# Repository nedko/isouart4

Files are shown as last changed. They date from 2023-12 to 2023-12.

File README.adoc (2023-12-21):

:notitle:
:keywords: isouart4
:docinfo: private-head,private-header

= isouart4 - Galvanically Isolated USB attached Quad UART

isouart4 - OSHW Galvanically Isolated USB attached Quad UART

.WORK IN PROGRESS
[NOTE]
This is Work In Progress.

link:bom/ibom.html[BOM - Bill Of Materials]

link:isouart4_sch.pdf[Schematic PDF]

link:https://gitea.ladish.org/nedko/isouart4[Project files] for link:https://kicad.org/[KiCAD]

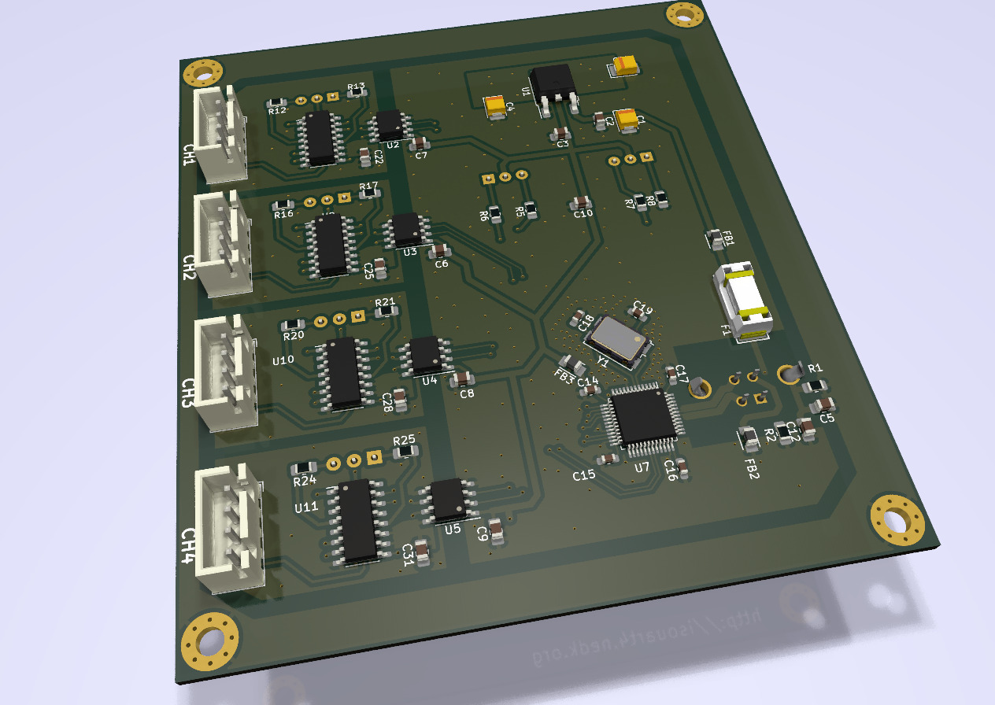
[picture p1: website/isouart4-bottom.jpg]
PCB bottom


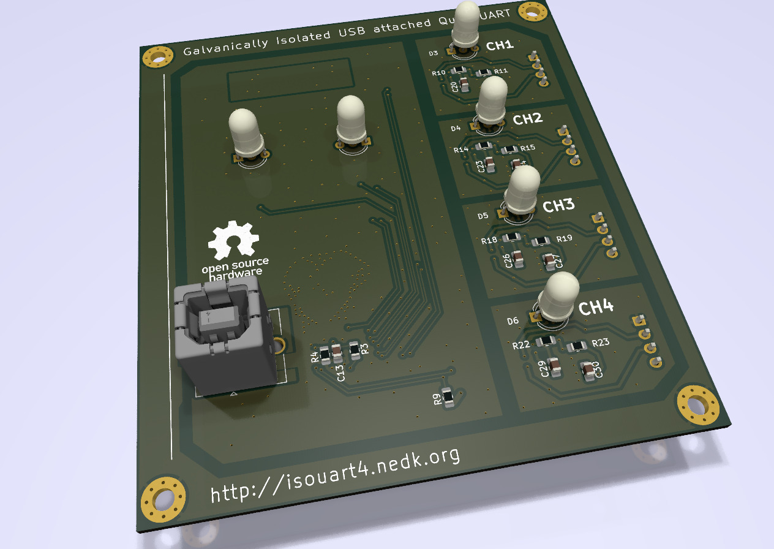
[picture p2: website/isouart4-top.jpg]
PCB top


== See also

 * link:https://github.com/hexeguitar/4WD_UART[4WD_UART by Piotr Zapart] is similar project that heavily influenced isouart4 design

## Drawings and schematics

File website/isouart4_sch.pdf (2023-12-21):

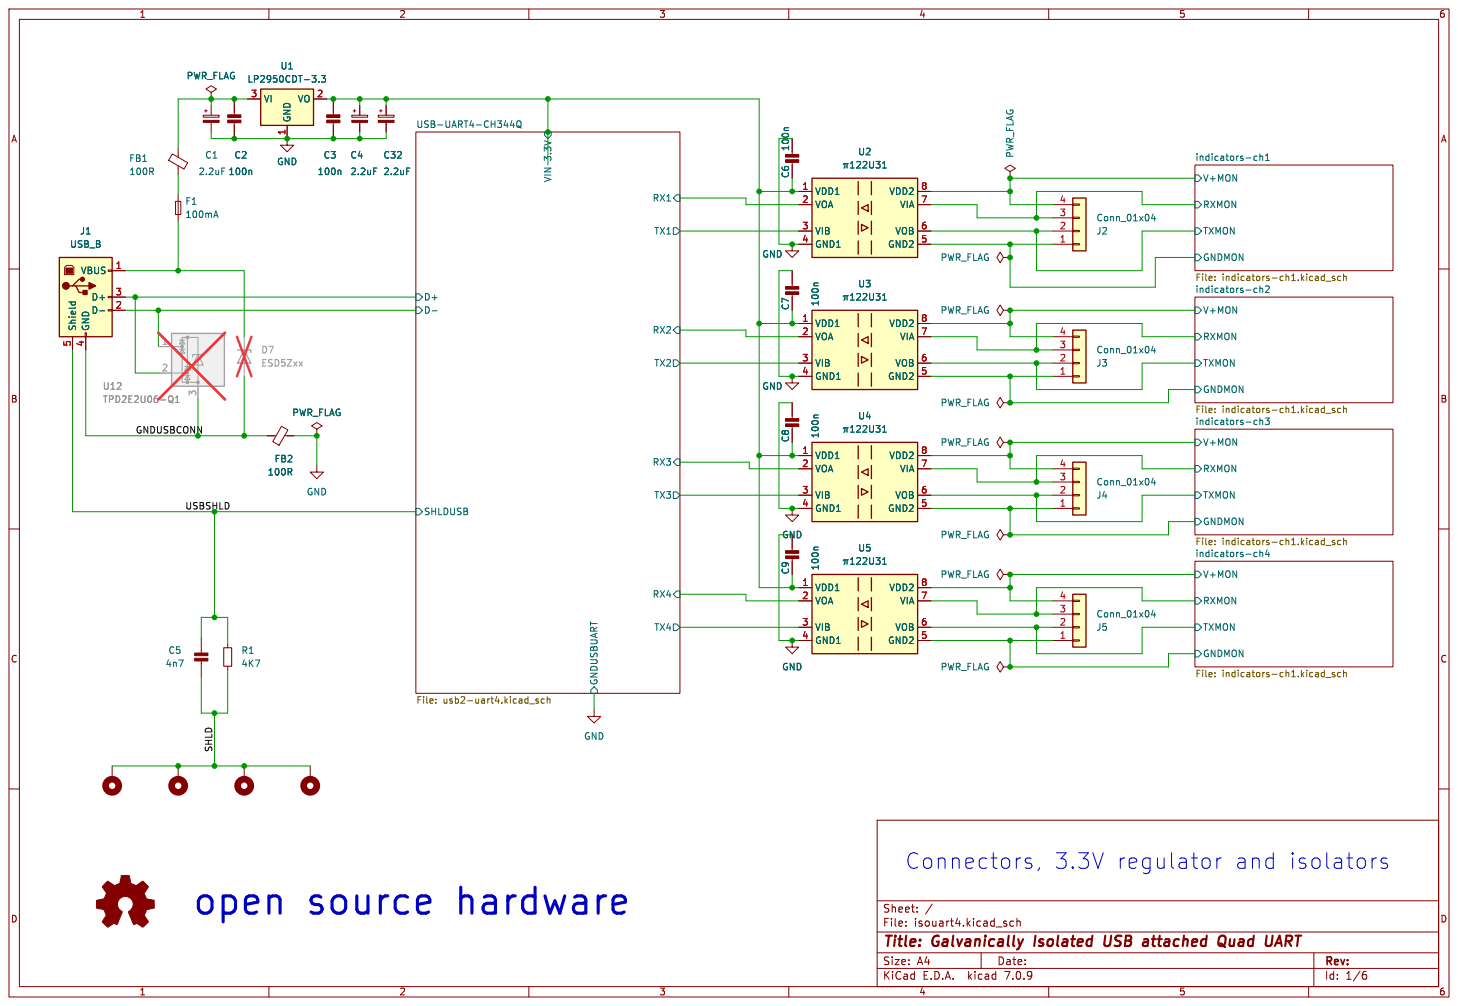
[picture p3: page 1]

indicators-ch3 File: indicators-ch1.kicad_sch RXMON

Id: 1/6 Title: Galvanically Isolated USB attached Quad UART

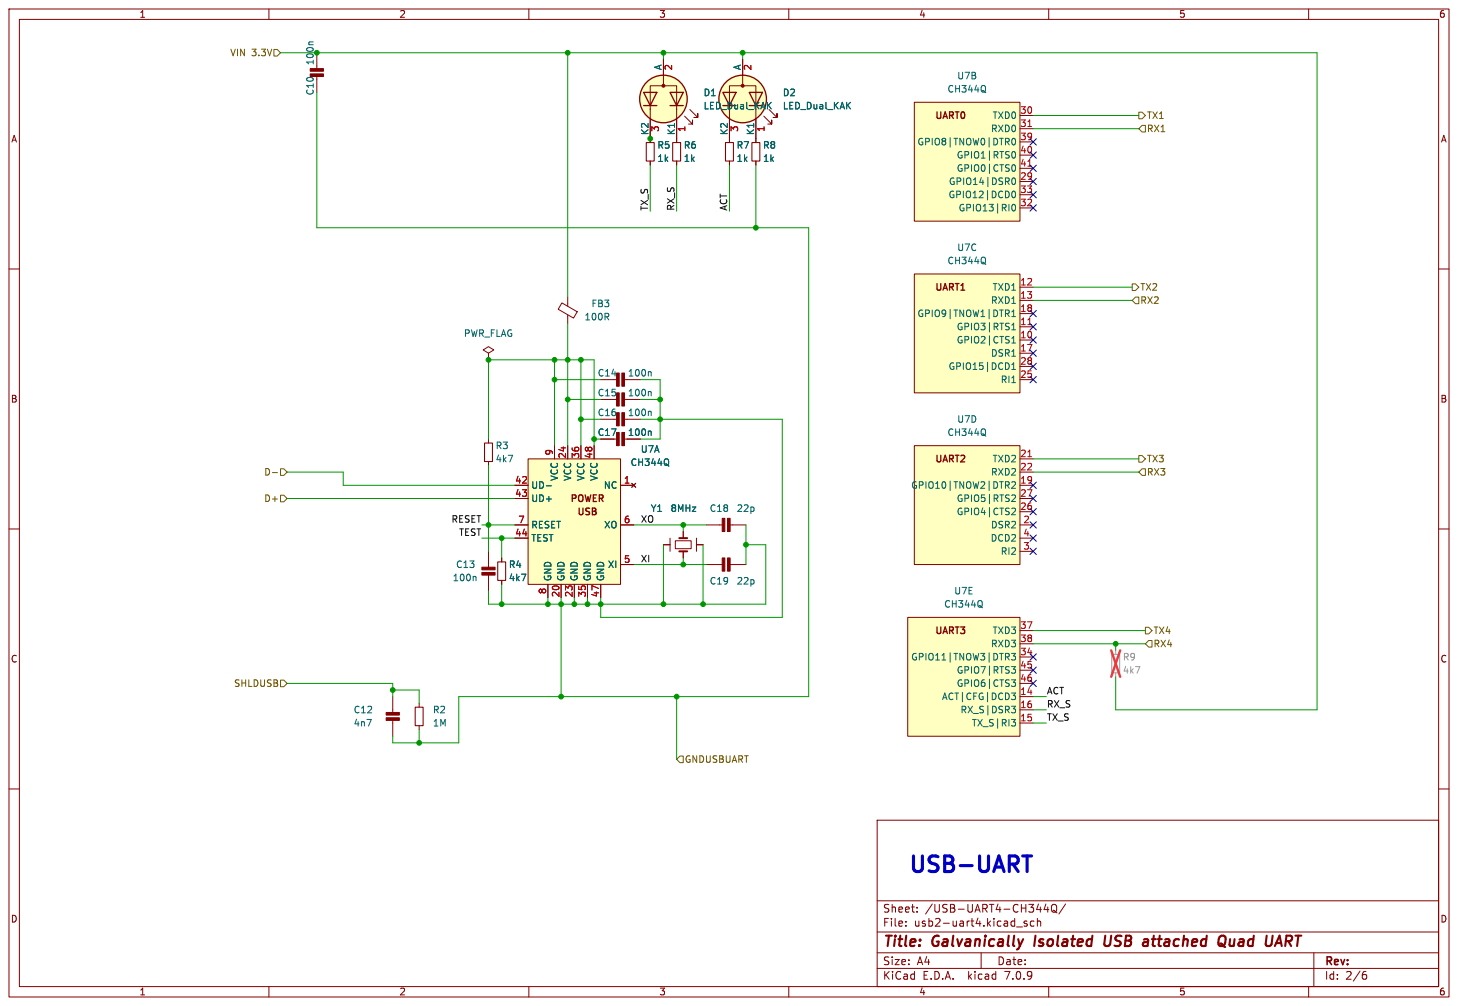
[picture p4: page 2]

File: usb2-uart4.kicad_sch Sheet: /USB-UART4-CH344Q/
Id: 2/6 Title: Galvanically Isolated USB attached Quad UART

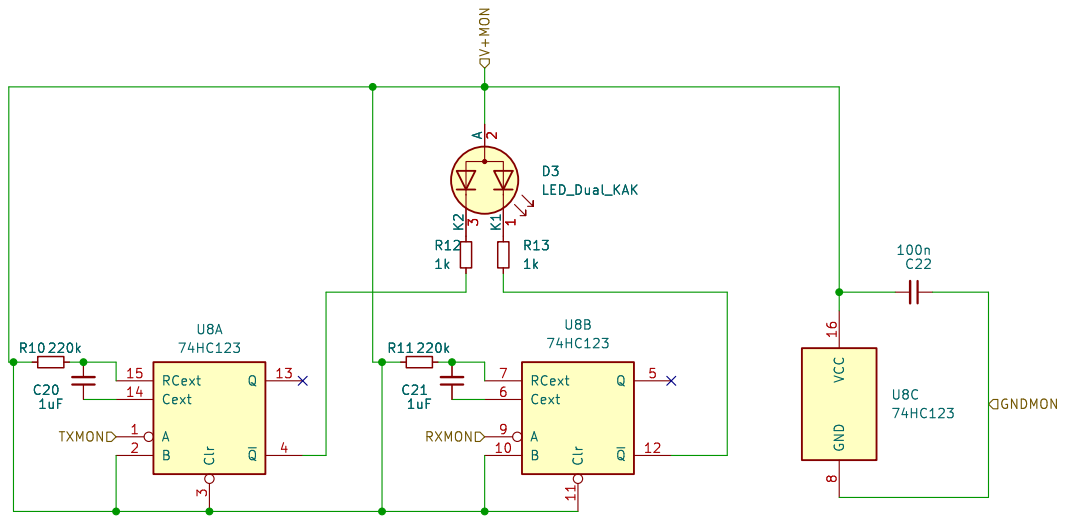
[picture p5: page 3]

File: indicators-ch1.kicad_sch Sheet: /indicators-ch1/ B

Id: 4/6 Title: Galvanically Isolated USB attached Quad UART

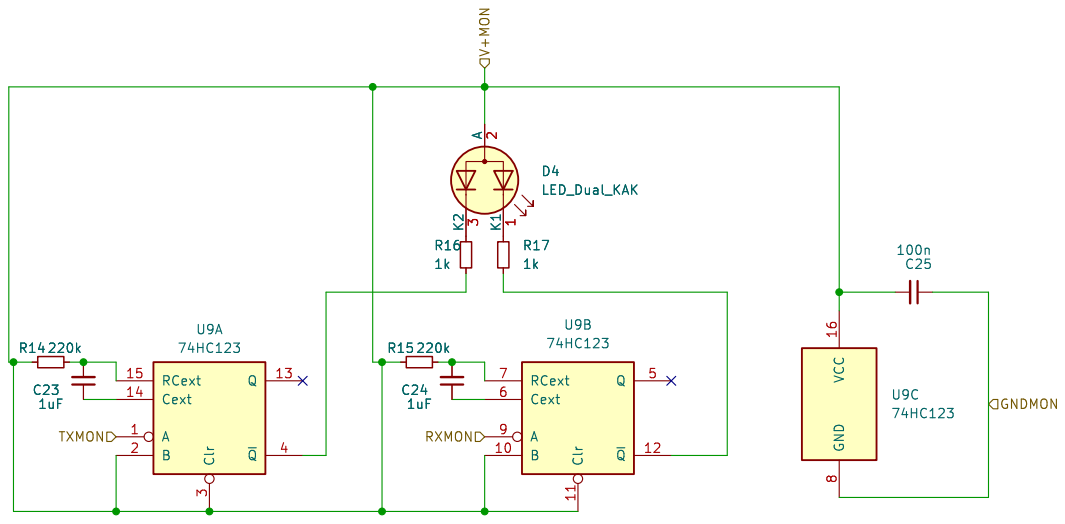
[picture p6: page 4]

File: indicators-ch1.kicad_sch Sheet: /indicators-ch2/ B

Id: 5/6 Title: Galvanically Isolated USB attached Quad UART

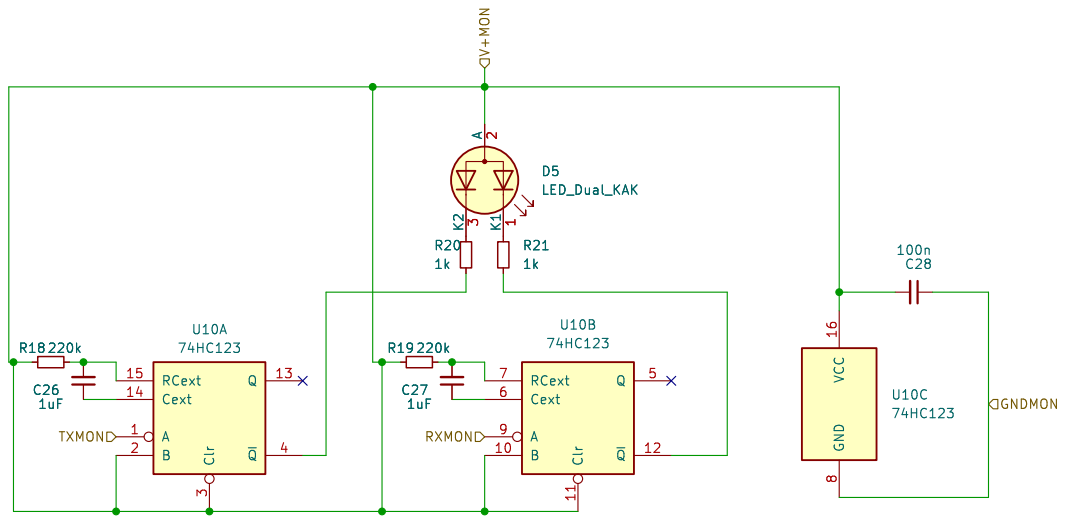
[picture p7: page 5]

File: indicators-ch1.kicad_sch Sheet: /indicators-ch3/ B

Id: 6/6 Title: Galvanically Isolated USB attached Quad UART

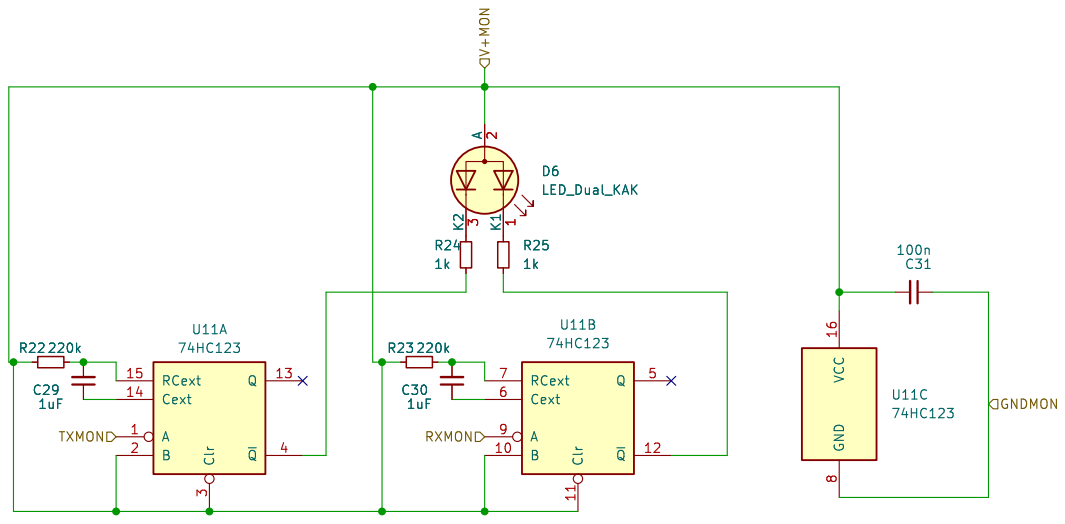
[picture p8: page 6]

File: indicators-ch1.kicad_sch Sheet: /indicators-ch4/ B

Id: 7/6 Title: Galvanically Isolated USB attached Quad UART

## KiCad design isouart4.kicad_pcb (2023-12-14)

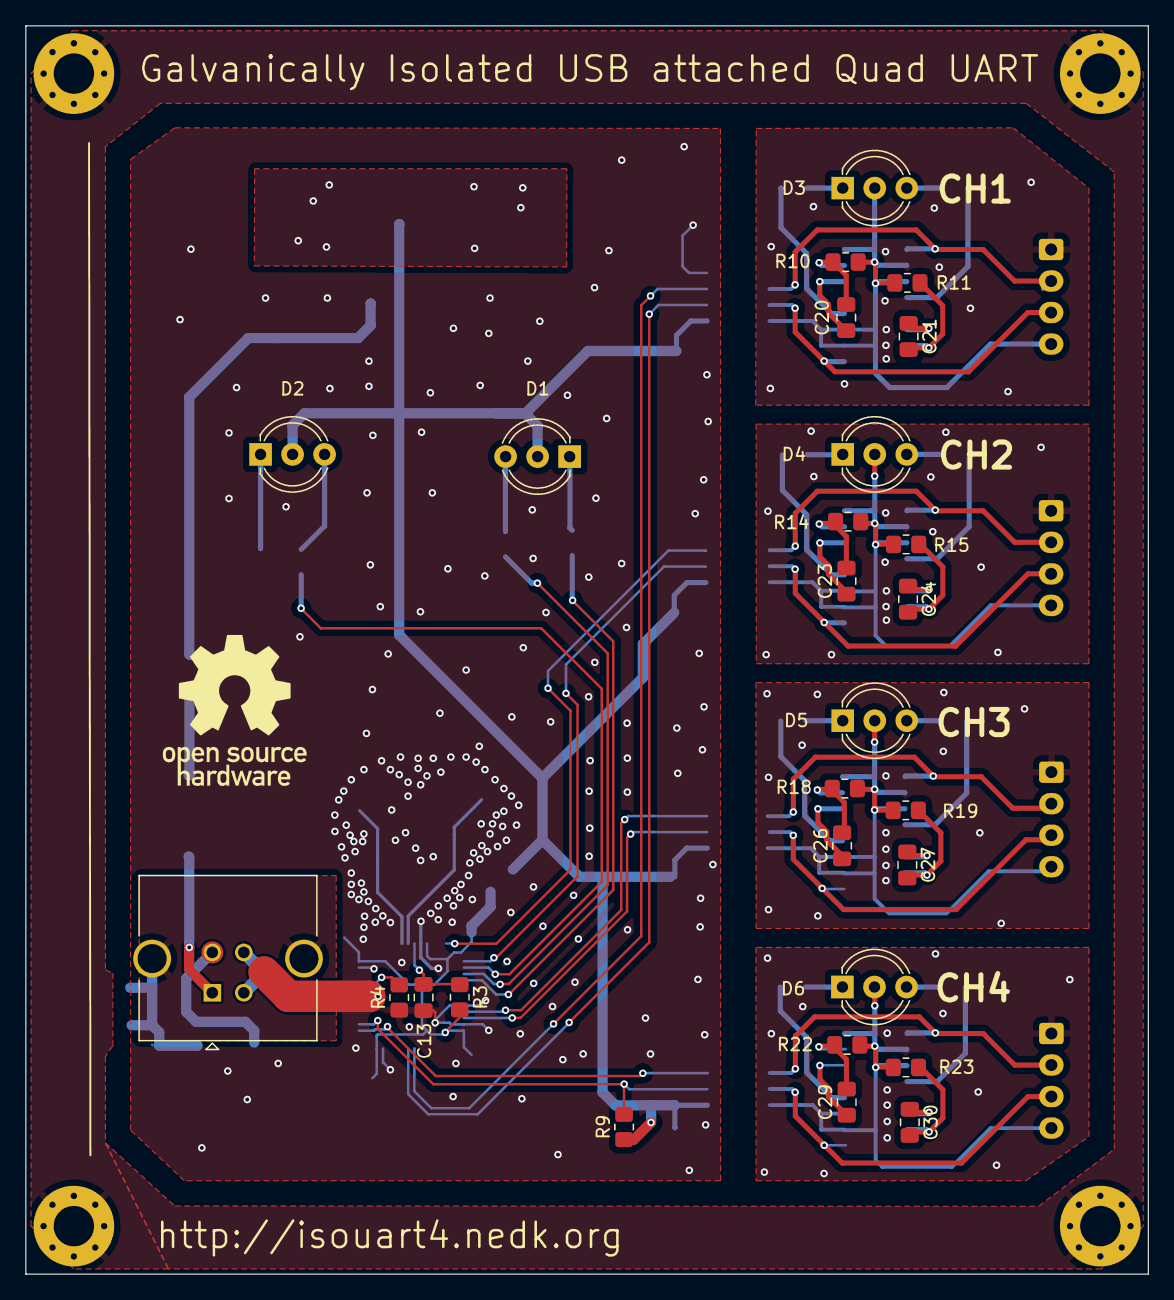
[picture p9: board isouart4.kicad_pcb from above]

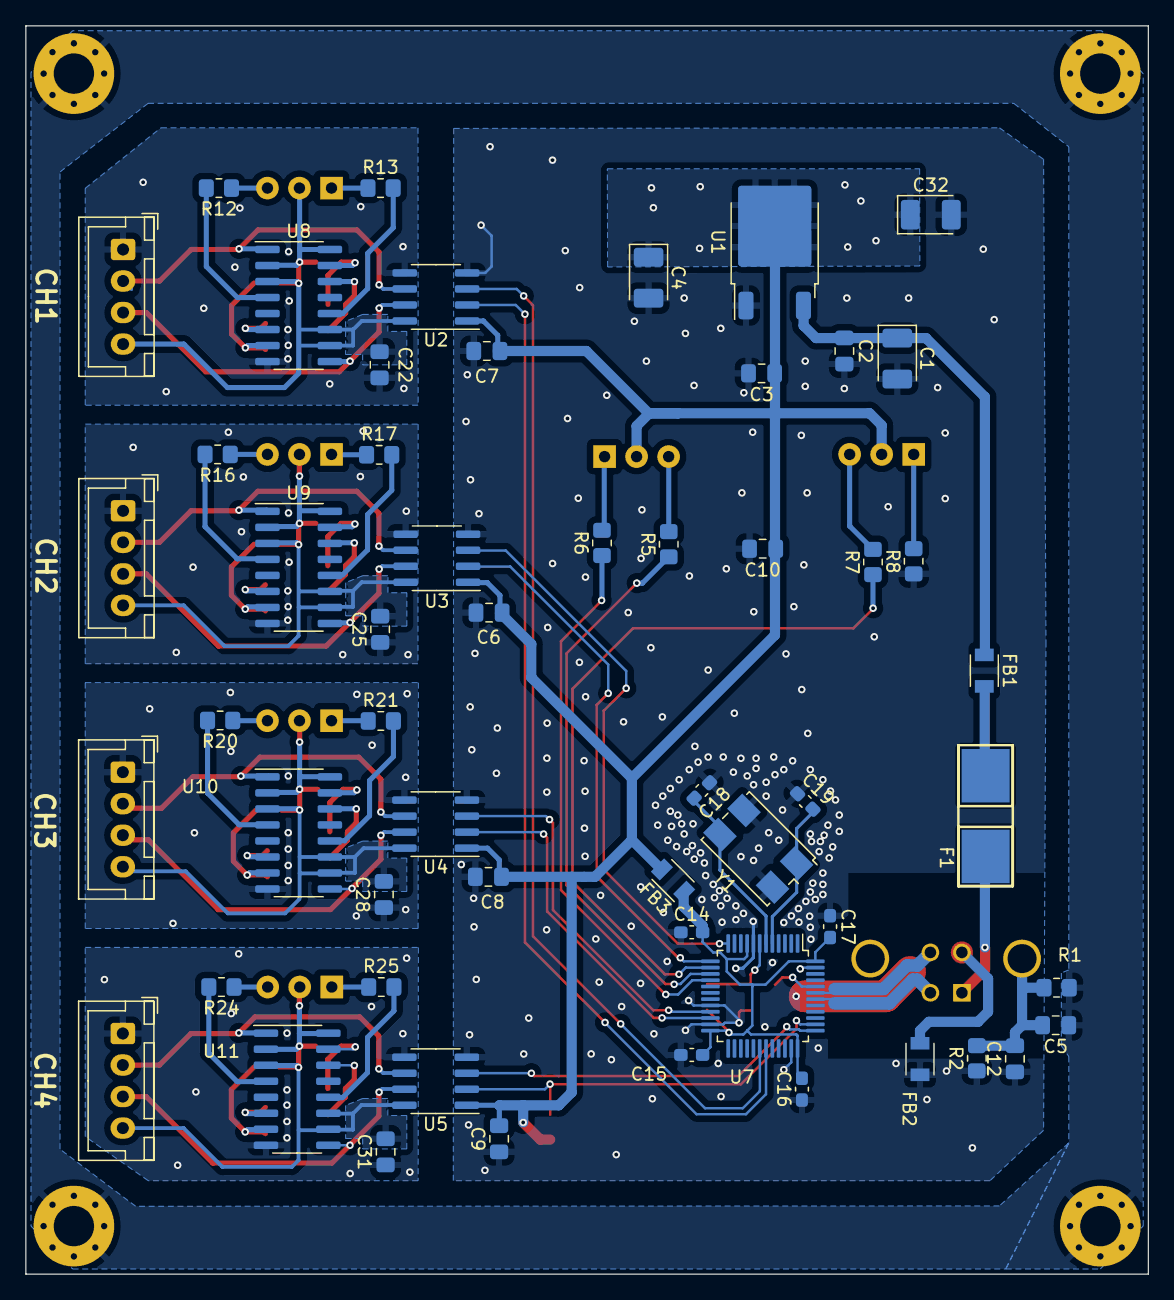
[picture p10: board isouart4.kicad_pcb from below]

Board: 2 copper layers, 89.0 x 99.0 mm, 87 parts (55 on the bottom side), 78 nets.

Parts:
C1, C4, C32: 2.2uF; CP_EIA-3528-15_AVX-H_Pad1.50x2.35mm_HandSolder
C2, C3, C6, C7, C8, C9, C10, C13, C22, C25, C28, C31: 100n; C_0805_2012Metric_Pad1.18x1.45mm_HandSolder
C5, C12: 4n7; C_0805_2012Metric_Pad1.18x1.45mm_HandSolder
C14, C15, C16, C17: 100n; C_0603_1608Metric_Pad1.08x0.95mm_HandSolder
C18, C19: 22p; C_0603_1608Metric_Pad1.08x0.95mm_HandSolder
C20, C21, C23, C24, C26, C27, C29, C30: 1uF; C_0805_2012Metric_Pad1.18x1.45mm_HandSolder
D1, D2, D3, D4, D5, D6: LED_Dual_KAK; LED_D5.0mm-3
F1: 100mA; FuseX
FB1, FB2, FB3: 100R; FB_0805_2012Metric
H1, H2, H3, H4: MountingHole; MountingHole_3.2mm_M3_Pad_Via
J1: USB_B; USB_B_TE_5787834_Vertical
J2, J3, J4, J5: Conn_01x04; JST_XH_B4B-XH-A_1x04_P2.50mm_Vertical
LOGO1: OSHW
R1: 4K7; R_0805_2012Metric_Pad1.20x1.40mm_HandSolder
R2: 1M; R_0805_2012Metric_Pad1.20x1.40mm_HandSolder
R3, R4, R9: 4k7; R_0805_2012Metric_Pad1.20x1.40mm_HandSolder
R5, R6, R7, R8, R12, R13, R16, R17, R20, R21, R24, R25: 1k; R_0805_2012Metric_Pad1.20x1.40mm_HandSolder
R10, R11, R14, R15, R18, R19, R22, R23: 220k; R_0805_2012Metric_Pad1.20x1.40mm_HandSolder
U1: LP2950CDT-3.3; TO-252-2
U2, U3, U4, U5: π122U31; SOIC-8_3.9x4.9mm_P1.27mm
U7: CH344Q; LQFP-48_7x7mm_P0.5mm
U8, U9, U10, U11: 74HC123; SOIC-16_3.9x9.9mm_P1.27mm
Y1: 8MHz; Crystal_SMD_7050-4Pin_7.0x5.0mm

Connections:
/GNDUSBCONN: FB2.1, J1.4 (GND)
/SHLD: C5.1, H1.1, H2.1, H3.1, H4.1, R1.1
/USB-UART4-CH344Q/ACT: R7.1, U7.14 (ACT|CFG|DCD3)
/USB-UART4-CH344Q/D+: J1.3 (D+), U7.43 (UD+)
/USB-UART4-CH344Q/D-: J1.2 (D-), U7.42 (UD-)
/USB-UART4-CH344Q/RESET: C13.2, R3.1, U7.7 (RESET)
/USB-UART4-CH344Q/RX1: U2.2 (VOA), U7.31 (RXD0)
/USB-UART4-CH344Q/RX2: U3.2 (VOA), U7.13 (RXD1)
/USB-UART4-CH344Q/RX3: U4.2 (VOA), U7.22 (RXD2)
/USB-UART4-CH344Q/RX4: R9.2, U5.2 (VOA), U7.38 (RXD3)
/USB-UART4-CH344Q/RX_S: R6.1, U7.16 (RX_S|DSR3)
/USB-UART4-CH344Q/TEST: R4.2, U7.44 (TEST)
/USB-UART4-CH344Q/TX1: U2.3 (VIB), U7.30 (TXD0)
/USB-UART4-CH344Q/TX2: U3.3 (VIB), U7.12 (TXD1)
/USB-UART4-CH344Q/TX3: U4.3 (VIB), U7.21 (TXD2)
/USB-UART4-CH344Q/TX4: U5.3 (VIB), U7.37 (TXD3)
/USB-UART4-CH344Q/TX_S: R5.1, U7.15 (TX_S|RI3)
/USB-UART4-CH344Q/VIN 3.3V: C3.1, C4.1, C6.2, C7.2, C8.2, C9.2, C10.1, C32.1, D1.2 (A), D2.2 (A), FB3.2, R9.1, U1.2 (VO), U2.1 (VDD1), U3.1 (VDD1), U4.1 (VDD1), U5.1 (VDD1)
/USB-UART4-CH344Q/XI: C19.2, U7.5 (XI), Y1.1
/USB-UART4-CH344Q/XO: C18.2, U7.6 (XO), Y1.3
/USBSHLD: C5.2, C12.2, J1.5 (Shield), R1.2, R2.2
/indicators-ch1/GNDMON: C22.1, J2.1, U2.5 (GND2), U8.8 (GND)
/indicators-ch1/RXMON: J2.3, U2.7 (VIA), U8.9 (A)
/indicators-ch1/TXMON: J2.2, U2.6 (VOB), U8.1 (A)
/indicators-ch1/V+MON: C22.2, D3.2 (A), J2.4, R10.1, R11.1, U2.8 (VDD2), U8.2 (B), U8.3 (Clr), U8.10 (B), U8.11 (Clr), U8.16 (VCC)
/indicators-ch2/GNDMON: C25.1, J3.1, U3.5 (GND2), U9.8 (GND)
/indicators-ch2/RXMON: J3.3, U3.7 (VIA), U9.9 (A)
/indicators-ch2/TXMON: J3.2, U3.6 (VOB), U9.1 (A)
/indicators-ch2/V+MON: C25.2, D4.2 (A), J3.4, R14.1, R15.1, U3.8 (VDD2), U9.2 (B), U9.3 (Clr), U9.10 (B), U9.11 (Clr), U9.16 (VCC)
/indicators-ch3/GNDMON: C28.1, J4.1, U4.5 (GND2), U10.8 (GND)
/indicators-ch3/RXMON: J4.3, U4.7 (VIA), U10.9 (A)
/indicators-ch3/TXMON: J4.2, U4.6 (VOB), U10.1 (A)
/indicators-ch3/V+MON: C28.2, D5.2 (A), J4.4, R18.1, R19.1, U4.8 (VDD2), U10.2 (B), U10.3 (Clr), U10.10 (B), U10.11 (Clr), U10.16 (VCC)
/indicators-ch4/GNDMON: C31.1, J5.1, U5.5 (GND2), U11.8 (GND)
/indicators-ch4/RXMON: J5.3, U5.7 (VIA), U11.9 (A)
/indicators-ch4/TXMON: J5.2, U5.6 (VOB), U11.1 (A)
/indicators-ch4/V+MON: C31.2, D6.2 (A), J5.4, R22.1, R23.1, U5.8 (VDD2), U11.2 (B), U11.3 (Clr), U11.10 (B), U11.11 (Clr), U11.16 (VCC)
GND: C1.2, C2.2, C3.2, C4.2, C6.1, C7.1, C8.1, C9.1, C10.2, C12.1, C13.1, C14.1, C15.1, C16.1, C17.1, C18.1, C19.1, C32.2, FB2.2, R2.1, R4.1, R8.1, U1.1 (GND), U2.4 (GND1), U3.4 (GND1), U4.4 (GND1), U5.4 (GND1), U7.8 (GND), U7.20 (GND), U7.23 (GND), U7.35 (GND), U7.47 (GND), Y1.2 (GND), Y1.4 (GND)
unnamed: C14.2, C15.2, C16.2, C17.2, FB3.1, R3.2, U7.9 (VCC), U7.24 (VCC), U7.36 (VCC), U7.48 (VCC)
unnamed: D1.1 (K1), R6.2
unnamed: D1.3 (K2), R5.2
unnamed: D2.1 (K1), R8.2
unnamed: D2.3 (K2), R7.2
unnamed: D3.1 (K1), R13.1
unnamed: D3.3 (K2), R12.1
unnamed: D4.1 (K1), R17.1
unnamed: D4.3 (K2), R16.1
unnamed: D5.1 (K1), R21.1
unnamed: D5.3 (K2), R20.1
unnamed: D6.1 (K1), R25.1
unnamed: D6.3 (K2), R24.1
unnamed: F1.2, FB1.2
unnamed: F1.1, J1.1 (VBUS)
unnamed: C1.1, C2.1, FB1.1, U1.3 (VI)
unnamed: C20.1, U8.14 (Cext)
unnamed: C20.2, R10.2, U8.15 (RCext)
unnamed: R12.2, U8.4 (~Q)
unnamed: C21.1, U8.6 (Cext)
unnamed: C21.2, R11.2, U8.7 (RCext)
unnamed: R13.2, U8.12 (~Q)
unnamed: C23.1, U9.14 (Cext)
unnamed: C23.2, R14.2, U9.15 (RCext)
unnamed: R16.2, U9.4 (~Q)
unnamed: C24.1, U9.6 (Cext)
unnamed: C24.2, R15.2, U9.7 (RCext)
unnamed: R17.2, U9.12 (~Q)
unnamed: C26.1, U10.14 (Cext)
unnamed: C26.2, R18.2, U10.15 (RCext)
unnamed: R20.2, U10.4 (~Q)
unnamed: C27.1, U10.6 (Cext)
unnamed: C27.2, R19.2, U10.7 (RCext)
unnamed: R21.2, U10.12 (~Q)
unnamed: C29.1, U11.14 (Cext)
unnamed: C29.2, R22.2, U11.15 (RCext)
unnamed: R24.2, U11.4 (~Q)
unnamed: C30.1, U11.6 (Cext)
unnamed: C30.2, R23.2, U11.7 (RCext)
unnamed: R25.2, U11.12 (~Q)

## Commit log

2023-09-21 Initial draft of isouart4
    [ft4232-indicators.kicad_sch, indicators-ch1.kicad_sch, isouart4.kicad_pcb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]
2023-09-28 switch to CH344Q
    [ft4232-indicators.kicad_sch, isouart4.kicad_pcb, isouart4.kicad_sch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]
2023-10-04 More feng shui
    [isouart4.kicad_pcb, isouart4.kicad_sch, usb2-uart4.kicad_sch]
2023-10-07 pcb-route all uart channels
    [isouart4.kicad_pcb, isouart4.kicad_sch, usb2-uart4.kicad_sch]
2023-12-06 Flush latest changes
    [indicators-ch1.kicad_sch, isouart4.kicad_pcb, isouart4.kicad_sch]
2023-12-06 current website
2023-12-07 Update pcb raytraced renderings
2023-12-07 remove problematic vias
    [isouart4.kicad_pcb]
2023-12-07 Add π122U31 to the project lib
    [isouart4.kicad_pcb, isouart4.kicad_sch]
2023-12-07 H_passives:CAP_NP -> isouart4:CAP_NP
    [isouart4.kicad_sch, usb2-uart4.kicad_sch]
2023-12-07 Use the custom isouart4:Crystal_Small instead of Device:Crystal_Small
    [usb2-uart4.kicad_sch]
2023-12-07 remove X1
    [usb2-uart4.kicad_sch]
2023-12-07 Restore 0805 capacitor footprints; Use anotherguse/FuseX copy form isouart4 lib
    [isouart4.kicad_pcb, isouart4.kicad_sch, usb2-uart4.kicad_sch]
2023-12-07 add files for project lib tables; add FuseX too isouart4.pretty
2023-12-07 adjust plygon of isobarier keepout
    [isouart4.kicad_pcb]
2023-12-07 remove unused kicad_sch files
    [ft4232-indicators.kicad_sch, usb-power.kicad_sch]
2023-12-07 .gitignore generated and kicad lock files
2023-12-07 switch C28-C33 to 0603
    [isouart4.kicad_pcb, usb2-uart4.kicad_sch]
2023-12-07 Update pcb raytrace renders
2023-12-07 Fix ferrite bead 3D model paths
    [isouart4.kicad_pcb]
2023-12-07 Add 3D model for the 7050 xtal
    https://grabcad.com/library/crystal-smd-7050-4pin-7-0x5-0mm-1
    [isouart4.kicad_pcb]
2023-12-10 Nonfunctional changes to schematic (positions)
    [usb2-uart4.kicad_sch]
2023-12-10 Fix xtal 7050 footprint warning by creating isouart4 footprint copy
    [isouart4.kicad_pcb, usb2-uart4.kicad_sch]
2023-12-10 Fix FB footprint warning by creating isouart4 footprint copy
    [isouart4.kicad_pcb, isouart4.kicad_sch, usb2-uart4.kicad_sch]
2023-12-10 Fix Reference fields
    [isouart4.kicad_sch, usb2-uart4.kicad_sch]
2023-12-10 Add fuse footpront courtyard; TH->SMD
    [isouart4.kicad_pcb]
2023-12-10 Unignore all currently ignored pcb tests
2023-12-10 Adjust R1, C1 and C10 poisitions
    [isouart4.kicad_pcb, usb2-uart4.kicad_sch]
2023-12-10 pcb: adjust mounting hole positions; SHLD outer line at 0.4mm from edge
    [isouart4.kicad_pcb]
2023-12-11 adjust power filtering
    [isouart4.kicad_pcb, isouart4.kicad_sch, usb2-uart4.kicad_sch]
2023-12-12 AMS1117-3.3 -> LP2950CDT-3.3 (reduce usb downstream capacitance)
    [isouart4.kicad_pcb, isouart4.kicad_sch]
2023-12-12 adjust silkscreen and led positions; reannotate
    [indicators-ch1.kicad_sch, isouart4.kicad_pcb, isouart4.kicad_sch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]
2023-12-12 Add OSHW logo
    [isouart4.kicad_pcb]
2023-12-12 website: update pcb raytrace exports
2023-12-12 add kicad 3d view "E"
2023-12-12 website: Update pcb raytrace renders (crop)
2023-12-12 Switch main sheet of schematic from A3 to A4
    [isouart4.kicad_sch]
2023-12-12 Add some title text to the schematic sheets
    [indicators-ch1.kicad_sch, isouart4.kicad_sch, usb2-uart4.kicad_sch]
2023-12-12 Adjust OSHW logo to have footprint and use it
    [isouart4.kicad_pcb, isouart4.kicad_sch]
2023-12-13 Update website/isouart4_sch.pdf (kicad default colour style)
2023-12-13 isouart4.pretty/OSHW.kicad_mod: set exclude_from_bom allow_missing_courtyard
2023-12-13 increase via size to 0.6mm and via annular width to 0.13mm
    [isouart4.kicad_pcb]
2023-12-14 adjust regulator tantalum capacitors (1+3.3uF -> 3x2.2uF)
    [isouart4.kicad_pcb, isouart4.kicad_sch]
2023-12-15 rework ESD protection (handsolder sot-23 on USB connector)
    [isouart4.kicad_sch, usb2-uart4.kicad_sch]
2023-12-15 fix ESD protection wiring (now both D+ and D-)
    [isouart4.kicad_sch]
2023-12-21 website: update schematic pdf and pcb raytrace exports
2023-12-21 website: update pcb raytrace exports (jpg)
2023-12-21 website: hyperlink kicad.org
